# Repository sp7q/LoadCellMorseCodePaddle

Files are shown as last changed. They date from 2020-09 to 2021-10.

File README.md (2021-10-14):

# LoadCellMorseCodePaddle
Load cell morse code paddle

This is a concept of using load cell as Morse Code paddle
Advantages :
- easy mechanical apply
- no moving parts
- fast and quiet
- cheap - Trinket + laod cells + AD ~25$
- auto calibration - no readjustment needed

In TrinketShielPaddle folde You can find KiCAD files + production files ready to send to *PCB make comapny 

Some challenges during during construction :

Assumpion - max speed 100 WPM

Sume usefull link about timing:
https://morsecode.world/international/timing.html

100WPM - 1dot = 12ms

AD requirements : 
Refering to Nyquist–Shannon law https://en.wikipedia.org/wiki/Nyquist%E2%80%93Shannon_sampling_theorem sampling rate should be at least 167 SPS

Load cell gives differential voltage: ~0-1.5mV

ADS1115 - 16bit(12bit ADS1015), 860SPS, lowest range 256mV, Comparator, differential mesurement
- 860SPS - OK
- 16bit - OK - 0.0039mV/bit (ADS1015 - 0.0625mV/bit - too small resolution vs 0-1.5mV range)
- 256mV - bit too low (do You know some AD with gain >16 and built in comparator - then smaller resolution is requiered)
- Comparator - as a requierement ! - comparator output drives executive transistor directly
- Differential mesurement - requre for 4 wire load cell

Battery alert
  - battery should never drop below 3.0V
  - there is ~0.3V drop on diode+regulator (ATTINY85 should work properly till 2.7)
  - Vcc measure using internal 1.1 reference
  - 3.1 - drop = 2.8 = alert 
  - 3.0 - drop = alert + lock paddle 

TODO : 
- AD1115_wa lib cleaning
- other A/D ?
- i2c connection autodiagnose work on Arduino Nano but not on Trinket
- Fully printed housing + paddles will be nice addon (OpenSCAD)
- E/V/HST test - passed HST by SP7VV
- issue with charging circuit
- after some time of use in setup mode paddle start working in reverse mode, need to be pulled instead of pushed - partially done:
      -poor chineese load cell change their "zero" point in time, also beacuse of that new approach with autocalibration is done
      -setup part should done with same approach as well TBD

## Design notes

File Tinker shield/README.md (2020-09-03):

Shield for TRINKET ATTINY85

Found 2 bugs (03-09-2020 fixed):
 - output swapped
 - lack of pullup resistors on ALRT

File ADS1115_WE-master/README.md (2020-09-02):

# ADS1115_WE
An Arduino library for the 16-bit, 4 channel ADS1115 ADC with gain and alert functions.

I have have tried to optimize the library for convenience to use. If you try the examples I recommend to start with Single_Shot.ino. You'll find more details here soon: https://wolles-elektronikkiste.de/ads1115.

All features of the ADS1115 are implemented, including alert functions. 

If you like the library it would be cool if you can give it a star. If you find bugs, please inform me. 

/////////////////////////////////////////////////////////////////////////////////////////////////////////////

I've edited this lib to get raw data form AD instead of calculating mV

TODO :
- clean up and leave only function necessary for my project purpose

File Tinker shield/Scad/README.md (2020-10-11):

Some idea of mechanical solution and use as case aluminum profile 40x40x2 - 50mm long

U can also find paddles thata I used for this project - paddle is prepared for M3 holes in load cell

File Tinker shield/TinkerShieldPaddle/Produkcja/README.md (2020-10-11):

Production files that You can send directly to *PCB.com company

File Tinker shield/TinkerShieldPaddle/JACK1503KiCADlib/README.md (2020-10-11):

KiCAD lib for JACK socket

https://www.tme.eu/pl/details/1503-02/zlacza-jack/lumberg/1503-02/

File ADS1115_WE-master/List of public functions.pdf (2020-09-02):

Function | Parameters | what it does
void reset( ) | none | Resets the ADS1115. Be careful this function uses the I2C general call reset. Therefore all devices listening to general calls will be resetted.
bool init ( ) | none | Sets the Configuration Register to default values. Returns false if the ADS1115 is not connected
void setAlertPinMode( mode ) | ADS1115_ASSERT_AFTER_X with X = 1, 2, 4; or: ADS1115_DISABLE_ALERT (default) | When alert limits are set, this function defines after how many out of range samples the alarm pin will assert. When the alert pin is set to conversion ready alert, you also need call this function with any parameter except ADS1115_DISABLE_ALERT. Which one you choose exactly doesn't matter.
void setAlertLatch( mode ) | ADS1115_LATCH_DISABLED ADS1115_LATCH_ENABLED | When the alert latch is enabled, the alert pin will be active until you call clearAlert or until you call getResult_V / getResult_mV. When disabled, the alert pin will be deactivated, if the results are within limits.
void setAlertPol( polarity ) | ADS1115_ACTIVE_HIGH ADS1115_ACTIVE_LOW (default) | The alert pin can be set active-high or active-low
void setAlertModeAndLimit_V( mode, upper limit, lower limit ) | mode: ADS1115_MAX_LIMIT ADS1115_WINDOW limits: voltage [V] | In max limit mode the alert pin will be active when the max limit is exceeded. The pin will be deactivated again, when the the results are below the lower limit (if latch is not enabled) In the window mode the alert pin will be active when result are out of the window limits. It will be deactivated, when results are in the window limits again (if latch is not enabled).
void setConvRate( rate ) | ADS1115_X _SPS with X = 8, 16, 32, 64, 128, 250, 475, 860 | Sets the conversion rate in number of samples per second (SPS).
void setMeasureMode( mode ) | ADS1115_CONTINUOUS ADS1115_SINGLE | Sets continuous or single-shot mode. In single-shot mode the measurements need to be triggered manually (startSingleMeasurement). After a single-shot measurement the device goes into power-down mode.
void setVoltageRange_mV( range ) | ADS1115_RANGE_X with X = 6144, 4096, 2048, 1024, 0512, 0256 | Sets voltage range in mV and therefore the gain amplifier. The range is alway from -X to +X. Voltages applied to the input pins shall not exceed VCC + 0.3 Volt. If you change the range the compare registers will be updated automatically.
void setCompareChannels( ) | ADS1115_COMP_X with X = 0_1, 0_2, 1_3, 2_3, 0_GND, 1_GND, 2_GND, 3_GND | Sets the channels to be compared channels to be compared to GND
bool isBusy( ) | none | Reads the Conversion Ready flag. Works only in single-shot mode.
void startSingleMeasurement( ) | none | Triggers a single-shot measurement.
void getResult_V( ) / getResult_mV( ) | none | Returns the result currently available in the conversion register either in Volt or Millivolt. It does not wait for the current conversion to be completed.
void setAlertPinToConversionReady( ) | none | The alert pin will be active when a conversion is completed. You will also need to call the setAlertPinMode function. You can either use the alert pin for limit alerts or conversion ready alerts, not both in parallel.
void clearAlert( ) | none | When the alert latch is enabled, the alert will be active until you call this function or until you call getResult_V / getResult_mV.

## List of commands (public functions) of the ADS1115_WE library

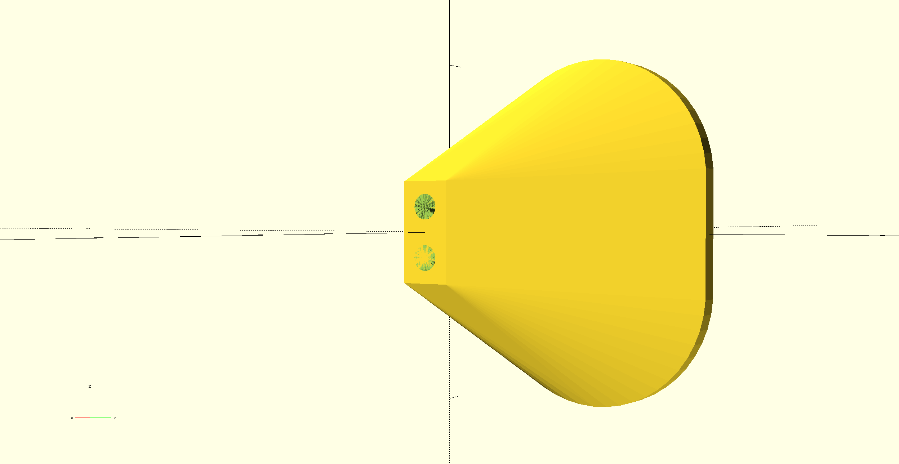
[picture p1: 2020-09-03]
Tinker shield/Scad/paddleuni_view.png

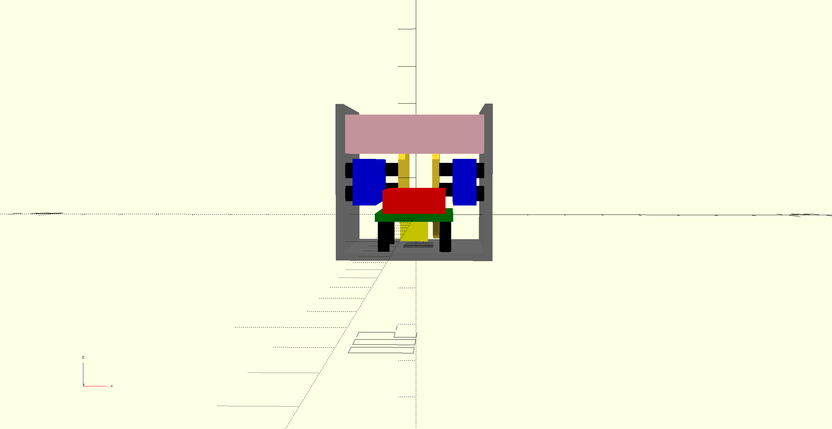
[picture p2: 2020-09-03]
Tinker shield/Scad/view3.png

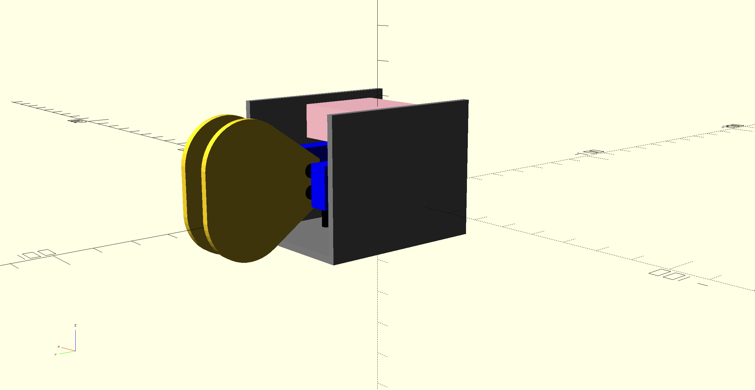
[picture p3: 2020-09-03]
Tinker shield/Scad/view1.png

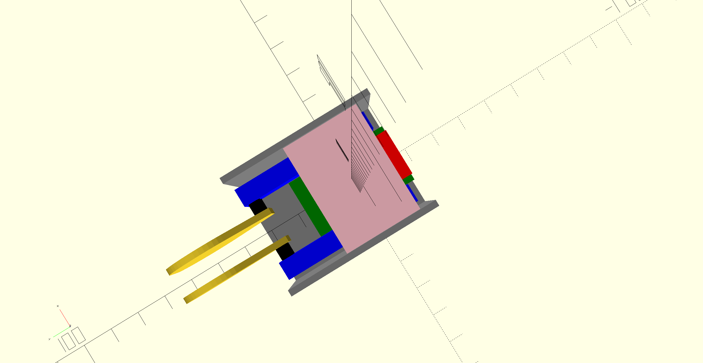
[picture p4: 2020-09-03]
Tinker shield/Scad/view2.png

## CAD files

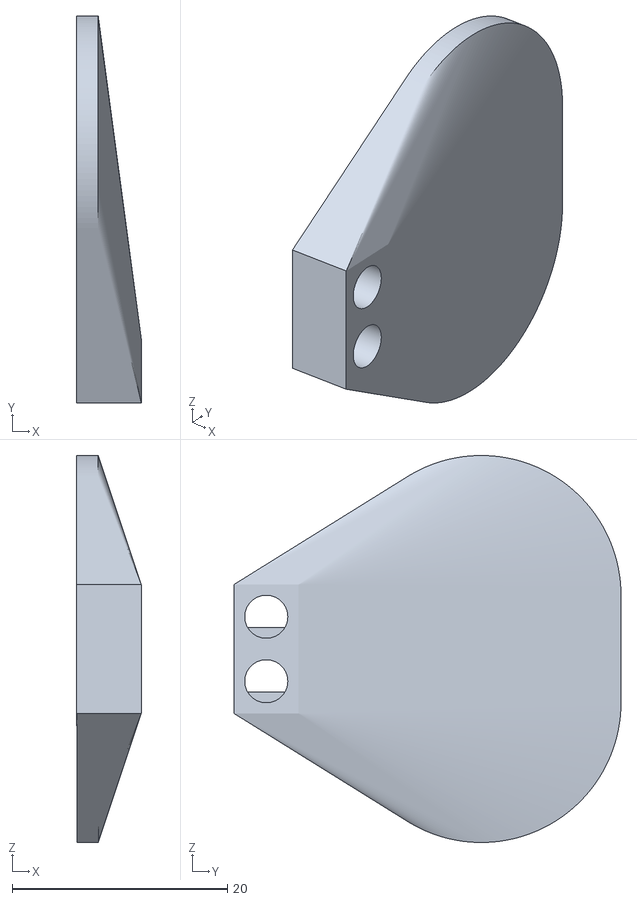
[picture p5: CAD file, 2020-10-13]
Tinker shield/Scad/paddleUniM4.stl
6.00 x 36.0 x 36.0

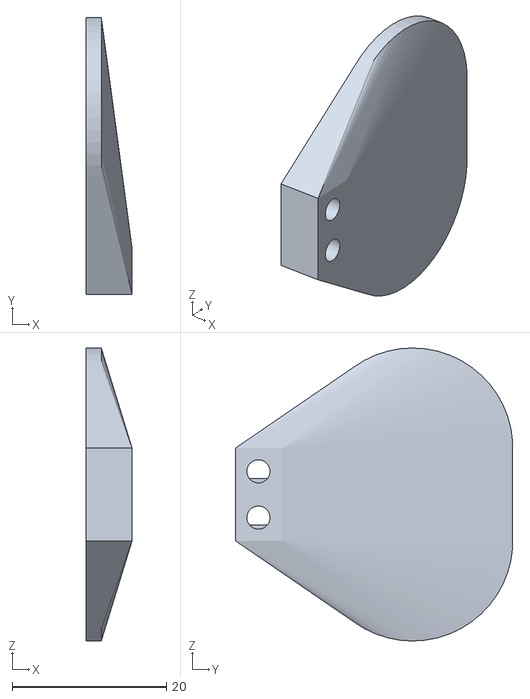
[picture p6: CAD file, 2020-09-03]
Tinker shield/Scad/paddleUni.stl
6.00 x 36.0 x 38.0

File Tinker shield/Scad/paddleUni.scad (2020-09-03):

difference(){
//otwor pod srube    


hull(){
translate([2,0,0]){
cube([6,6,12],true);    
    }     

    
translate([0,20,6]){
rotate([0,90,0]){
cylinder(2,13,13,$fn=50,true);
}
}

translate([0,20,-6]){
rotate([0,90,0]){
cylinder(2,13,13,$fn=50,true);
}
}

}

translate([2,0,3]){
rotate([0,90,0]){
cylinder(6,1.5,1.5,$fn=50,true);
}
}

translate([0,0,3]){
rotate([0,90,0]){
cylinder(2,2,1.5,$fn=50,true);
}
}

translate([2,0,-3]){
rotate([0,90,0]){
cylinder(6,1.5,1.5,$fn=50,true);
}
}
translate([0,0,-3]){
rotate([0,90,0]){
cylinder(2,2,1.5,$fn=50,true);
}
}
}

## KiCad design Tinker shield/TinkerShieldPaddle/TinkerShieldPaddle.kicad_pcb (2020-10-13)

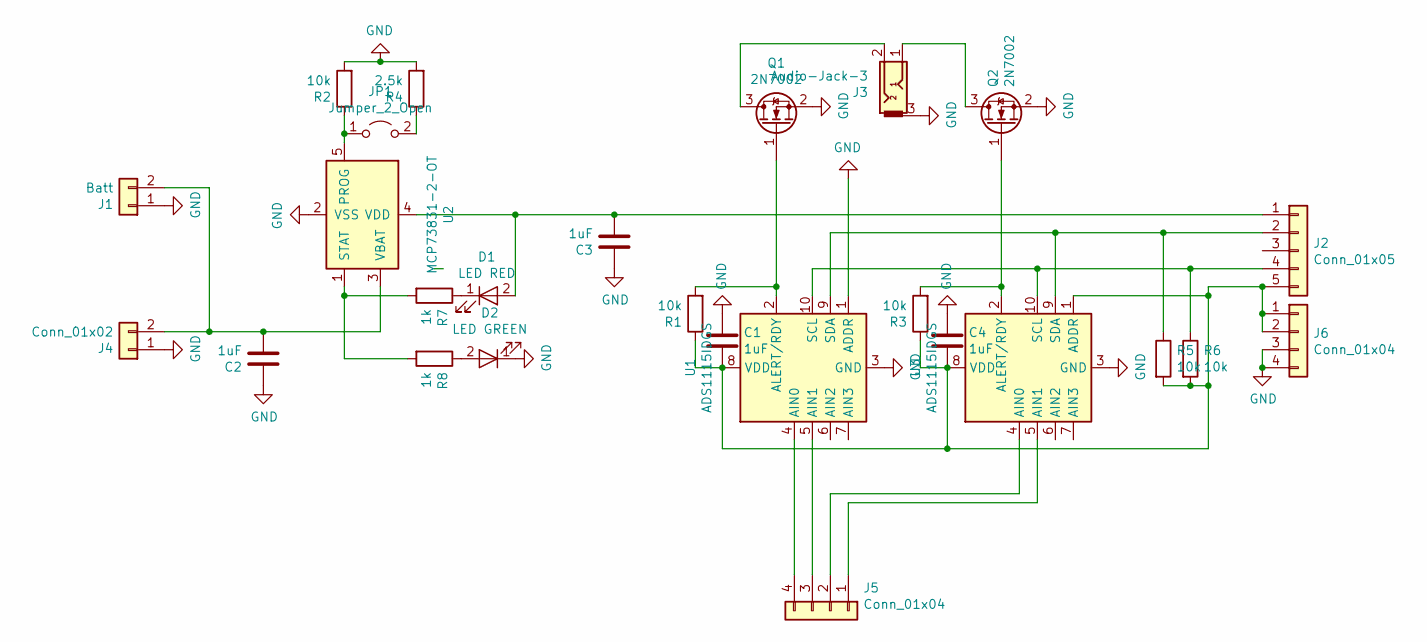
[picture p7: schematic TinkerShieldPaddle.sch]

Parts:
C1, C2, C3, C4: 1uF; C_0805_2012Metric_Pad1.15x1.40mm_HandSolder
D1: LED RED; D_0805_2012Metric_Pad1.15x1.40mm_HandSolder
D2: LED GREEN; D_0805_2012Metric_Pad1.15x1.40mm_HandSolder
J1: Batt; PinHeader_1x02_P2.54mm_Vertical
J2: Conn_01x05; PinHeader_1x05_P2.54mm_Vertical
J3: Audio-Jack-3; Jack_3.5mm_1503_Horizontal
J4: Conn_01x02; PinHeader_1x02_P2.54mm_Vertical
J5, J6: Conn_01x04; PinHeader_1x04_P2.54mm_Vertical
JP1: Jumper_2_Open; SolderJumper-2_P1.3mm_Open_RoundedPad1.0x1.5mm
Q1, Q2: 2N7002; SOT-23
R1, R2, R3, R5, R6: 10k; R_0805_2012Metric_Pad1.15x1.40mm_HandSolder
R4: 2.5k; R_0805_2012Metric_Pad1.15x1.40mm_HandSolder
R7, R8: 1k; R_0805_2012Metric_Pad1.15x1.40mm_HandSolder
U1, U3: ADS1115IDGS; TSSOP-10_3x3mm_P0.5mm
U2: MCP73831-2-OT; SOT-23-5_HandSoldering

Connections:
GND: C1.1, C2.1, C3.1, C4.1, D2.1 (K), J1.1, J3.3, J4.1, J6.3, J6.4, Q1.2 (S), Q2.2 (S), R2.2, R4.2, U1.1 (ADDR), U1.3 (GND), U2.2 (VSS), U3.3 (GND)
unnamed: C1.2, C4.2, J2.5, J6.1, J6.2, R1.1, R3.1, R5.2, R6.2, U1.8 (VDD), U3.1 (ADDR), U3.8 (VDD)
unnamed: C2.2, J1.2, J4.2, U2.3 (VBAT)
unnamed: C3.2, D1.2 (A), J2.1, U2.4 (VDD)
unnamed: D1.1 (K), R7.1
unnamed: D2.2 (A), R8.1
unnamed: J2.2, R5.1, U1.9 (SDA), U3.9 (SDA)
unnamed: J2.4, R6.1, U1.10 (SCL), U3.10 (SCL)
unnamed: J3.1, Q2.3 (D)
unnamed: J3.2, Q1.3 (D)
unnamed: J5.1, U3.5 (AIN1)
unnamed: J5.2, U3.4 (AIN0)
unnamed: J5.3, U1.5 (AIN1)
unnamed: J5.4, U1.4 (AIN0)
unnamed: JP1.1 (A), R2.1, U2.5 (PROG)
unnamed: JP1.2 (B), R4.1
unnamed: Q1.1 (G), R1.2, U1.2 (ALERT/RDY)
unnamed: Q2.1 (G), R3.2, U3.2 (ALERT/RDY)
unnamed: R7.2, R8.2, U2.1 (STAT)

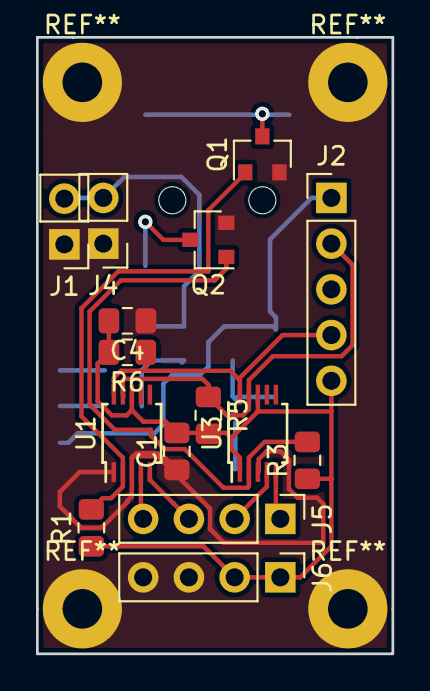
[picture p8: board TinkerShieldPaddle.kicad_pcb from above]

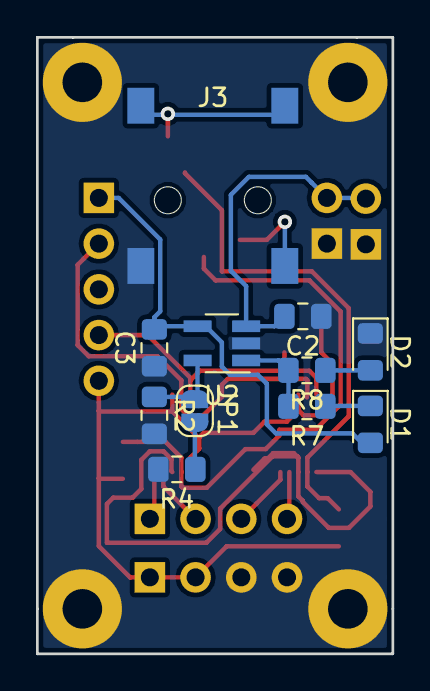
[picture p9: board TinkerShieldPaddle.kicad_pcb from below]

Board: 2 copper layers, 19.8 x 34.2 mm, 26 parts (11 on the bottom side), 19 nets.

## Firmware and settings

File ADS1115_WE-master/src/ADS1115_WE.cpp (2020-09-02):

/*****************************************
* This is a library for the ADS1115 A/D Converter
*
* You'll find an example which should enable you to use the library. 
*
* You are free to use it, change it or build on it. In case you like 
* it, it would be cool if you give it a star.
* 
* If you find bugs, please inform me!
* 
* Written by Wolfgang (Wolle) Ewald
* https://wolles-elektronikkiste.de
*
*******************************************/

#include "ADS1115_WE.h"

ADS1115_WE::ADS1115_WE(int addr){
	i2cAddress = addr;
}

ADS1115_WE::ADS1115_WE(){
	i2cAddress = 0x48;
}

void ADS1115_WE::reset(){
	Wire.beginTransmission(0);
	Wire.write(0x06);
	Wire.endTransmission();
}

bool ADS1115_WE::init(){	
	Wire.beginTransmission(i2cAddress);
	uint8_t success = Wire.endTransmission();
	if(success){
		return 0;
	}
	writeRegister(ADS1115_CONFIG_REG, ADS1115_REG_RESET_VAL);
	setVoltageRange_mV(ADS1115_RANGE_2048);
	writeRegister(ADS1115_LO_THRESH_REG, 0x8000);
	writeRegister(ADS1115_HI_THRESH_REG, 0x7FFF);
	return 1;
}

void ADS1115_WE::setAlertPinMode(ADS1115_COMP_QUE mode){
	uint16_t currentConfReg = readRegister(ADS1115_CONFIG_REG);
	currentConfReg &= ~(0x0003);	
	currentConfReg |= mode;
	writeRegister(ADS1115_CONFIG_REG, currentConfReg);
}

void ADS1115_WE::setAlertLatch(ADS1115_LATCH latch){
	uint16_t currentConfReg = readRegister(ADS1115_CONFIG_REG);
	currentConfReg &= ~(0x0004);	
	currentConfReg |= latch;
	writeRegister(ADS1115_CONFIG_REG, currentConfReg);
}

void ADS1115_WE::setAlertPol(ADS1115_ALERT_POL polarity){
	uint16_t currentConfReg = readRegister(ADS1115_CONFIG_REG);
	currentConfReg &= ~(0x0008);	
	currentConfReg |= polarity;
	writeRegister(ADS1115_CONFIG_REG, currentConfReg);
}

void ADS1115_WE::setAlertModeAndLimit_V(ADS1115_COMP_MODE mode, int hiThres, int loThres){
	uint16_t currentConfReg = readRegister(ADS1115_CONFIG_REG);
	currentConfReg &= ~(0x0010);	
	currentConfReg |= mode;
	writeRegister(ADS1115_CONFIG_REG, currentConfReg);
	//int16_t alertLimit = calcLimit(hiThres);
	int16_t alertLimit = hiThres;
	writeRegister(ADS1115_HI_THRESH_REG, alertLimit);
	//alertLimit = calcLimit(loThres);
	alertLimit = loThres;
	writeRegister(ADS1115_LO_THRESH_REG, alertLimit);
	
}

void ADS1115_WE::setConvRate(ADS1115_CONV_RATE rate){
	uint16_t currentConfReg = readRegister(ADS1115_CONFIG_REG);
	currentConfReg &= ~(0x00E0);	
	currentConfReg |= rate;
	writeRegister(ADS1115_CONFIG_REG, currentConfReg);
}
		
void ADS1115_WE::setMeasureMode(ADS1115_MEASURE_MODE mode){
	uint16_t currentConfReg = readRegister(ADS1115_CONFIG_REG);
	currentConfReg &= ~(0x0100);	
	currentConfReg |= mode;
	writeRegister(ADS1115_CONFIG_REG, currentConfReg);
}

void ADS1115_WE::setVoltageRange_mV(ADS1115_RANGE range){
	uint16_t currentVoltageRange = voltageRange;
	uint16_t currentConfReg = readRegister(ADS1115_CONFIG_REG);
	uint16_t currentRange = (currentConfReg >> 9) & 7;
	uint16_t currentAlertPinMode = currentConfReg & 3;
	
	setMeasureMode(ADS1115_SINGLE);
	
	switch(range){
		case ADS1115_RANGE_6144:
			voltageRange = 6144;
			break;
		case ADS1115_RANGE_4096:
			voltageRange = 4096;
			break;
		case ADS1115_RANGE_2048:
			voltageRange = 2048;
			break;
		case ADS1115_RANGE_1024:
			voltageRange = 1024;
			break;
		case ADS1115_RANGE_0512:
			voltageRange = 512;
			break;
		case ADS1115_RANGE_0256:
			voltageRange = 256;
			break;
	}
	
	if ((currentRange != range) && (currentAlertPinMode != ADS1115_DISABLE_ALERT)){
		int16_t alertLimit = readRegister(ADS1115_HI_THRESH_REG);
		alertLimit = alertLimit * (currentVoltageRange * 1.0 / voltageRange);
		writeRegister(ADS1115_HI_THRESH_REG, alertLimit);
		
		alertLimit = readRegister(ADS1115_LO_THRESH_REG);
		alertLimit = alertLimit * (currentVoltageRange * 1.0 / voltageRange);
		writeRegister(ADS1115_LO_THRESH_REG, alertLimit);
	}
	
	currentConfReg &= ~(0x0E00);	
	currentConfReg |= range;
	writeRegister(ADS1115_CONFIG_REG, currentConfReg);
}

void ADS1115_WE::setCompareChannels(ADS1115_MUX mux){
	uint16_t currentConfReg = readRegister(ADS1115_CONFIG_REG);
	currentConfReg &= ~(0x7000);	
	currentConfReg |= (mux);
	writeRegister(ADS1115_CONFIG_REG, currentConfReg);	
}
	
bool ADS1115_WE::isBusy(){
	uint16_t currentConfReg = readRegister(ADS1115_CONFIG_REG);
	return (!(currentConfReg>>15) & 1);
}
	
void ADS1115_WE::startSingleMeasurement(){
	uint16_t currentConfReg = readRegister(ADS1115_CONFIG_REG);
	currentConfReg |= (1 << 15);
	writeRegister(ADS1115_CONFIG_REG, currentConfReg);
}
	
float ADS1115_WE::getResult_V(){
	int16_t rawResult = readRegister(ADS1115_CONV_REG);
	float result = (rawResult * 1.0 / ADS1115_REG_FACTOR) * voltageRange/1000;
	return result;	
}

float ADS1115_WE::getResult_mV(){
	int16_t rawResult = readRegister(ADS1115_CONV_REG);
	//float result = (rawResult * 1.0 / ADS1115_REG_FACTOR) * voltageRange;
	float result = rawResult;
	return result;
}

int16_t ADS1115_WE::getResultWithRange(int16_t min, int16_t max){
	int16_t rawResult = readRegister(ADS1115_CONV_REG);
	//rawResult = (int) (rawResult * (voltageRange * 1.0 / 6144));
	int16_t result = 0;
	result = map(rawResult, 0, 32767, min, max);
	return result;
}


void ADS1115_WE::setAlertPinToConversionReady(){
	writeRegister(ADS1115_LO_THRESH_REG, (0<<15));
	writeRegister(ADS1115_HI_THRESH_REG, (1<<15));
}

void ADS1115_WE::clearAlert(){
	readRegister(ADS1115_CONV_REG);
}

/************************************************ 
	private functions
*************************************************/

int16_t ADS1115_WE::calcLimit(float rawLimit){
	int16_t limit = (int16_t)((rawLimit * ADS1115_REG_FACTOR / voltageRange)*1000);
	return limit;
}

uint8_t ADS1115_WE::writeRegister(uint8_t reg, uint16_t val){
  Wire.beginTransmission(i2cAddress);
  uint8_t lVal = val & 255;
  uint8_t hVal = val >> 8;
  Wire.write(reg);
  Wire.write(hVal);
  Wire.write(lVal);
  return Wire.endTransmission();
}
  
uint16_t ADS1115_WE::readRegister(uint8_t reg){
  uint8_t MSByte = 0, LSByte = 0;
  uint16_t regValue = 0;
  Wire.beginTransmission(i2cAddress);
  Wire.write(reg);
  Wire.endTransmission();
  Wire.requestFrom(i2cAddress,2);
  if(Wire.available()){
    MSByte = Wire.read();
    LSByte = Wire.read();
  }
  regValue = (MSByte<<8) + LSByte;
  return regValue;
}
	

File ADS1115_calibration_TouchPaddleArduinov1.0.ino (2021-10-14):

//ADS1115 - with calibration
// different approach - because battery is discharging and power supply vary in time calibration should be done on power up.
//to do - correct setup part
#include <tinysnore.h> //lib for ATTINY85
#include<ADS1115_WE.h> //lib was edited to give raw data instead of mV
#include<Wire.h>
#include <EEPROM.h>
#define I2C_ADDRESS_1 0x48
#define I2C_ADDRESS_2 0x49
ADS1115_WE adc(I2C_ADDRESS_1);
ADS1115_WE adc2(I2C_ADDRESS_2);

int result = 0;
int result2 = 0;
int resultb = 0;
int result2b = 0;
int led = 1; //1 - Trinket, 13 - Arduino
int sensitivity;
int sensitivityNow;
int leftNow;    
int rightNow;
int leftOn = 100;      //left paddle treshold
int leftOnAbs;   //left paddle absolute value treshold 
int leftOff = 80;     //left paddle off treshold
int rightOn = 100;     //right paddle treshold 
int rightOnAbs;   //right paddle absolute value treshold 
int rightOff = 80;   //right paddle off treshold
int hysteresis = 7; //hysteresis
int configMode = 0;
int time1;  //time for setup mode purpose
int time2;  //time for setup mode purpose

void setup() {
  pinMode(led, OUTPUT); 
  Wire.begin();
  //Serial.begin(250000);
  //this warning dont work on ATTINY dont know why ....
 /* 
  while(!adc2.init()){
        blink(20);
        delay(500);
//        Serial.println("adc2 not found");
  }

  while(!adc.init()){
        blink(40);
        delay(500);
//        Serial.println("adc not found");
  }
*/
  EEPROM.get(0,sensitivity);
//  EEPROM.get(2,leftOn);  
//  EEPROM.get(4,leftOff);  
//  EEPROM.get(6,rightOn); 
//  EEPROM.get(8,rightOff); 
  

  
  adc.setVoltageRange_mV(ADS1115_RANGE_0256); //amplifier gain
  adc.setCompareChannels(ADS1115_COMP_0_1); //differential measurement
  adc.setConvRate(ADS1115_860_SPS); //samples pre second 
  adc.setMeasureMode(ADS1115_CONTINUOUS); //Continous mode
  adc.setAlertPinMode(ADS1115_ASSERT_AFTER_1); //after how many measurments ALRT output is set
  adc.setAlertModeAndLimit_V(ADS1115_MAX_LIMIT, leftOn, leftOff); //Comparator values Hightreshold then LowTreshold 
  adc.setAlertPol(ADS1115_ACT_HIGH); //ALRT polarity

  adc2.setVoltageRange_mV(ADS1115_RANGE_0256); //amplifier gain
  adc2.setCompareChannels(ADS1115_COMP_0_1); //differential measurement
  adc2.setConvRate(ADS1115_860_SPS); //samples pre second 
  adc2.setMeasureMode(ADS1115_CONTINUOUS); //Continous mode
  adc2.setAlertPinMode(ADS1115_ASSERT_AFTER_1); //after how many measurments ALRT output is set
  adc2.setAlertModeAndLimit_V(ADS1115_MAX_LIMIT, rightOn, rightOff); //Comparator values Hightreshold then LowTreshold 
  adc2.setAlertPol(ADS1115_ACT_HIGH); //ALRT polarity
  delay(50);
  result = adc.getResult_mV(); 
  result2 = adc2.getResult_mV();
  blink(sensitivity);
  delay(500);
  resultb = adc.getResult_mV(); 
  result2b = adc2.getResult_mV();  
  if ((resultb > result) && (result2b > result2)){
      configMode = 1;
      blink(100);
      time1 = millis();
    }
  if (!configMode) {
    //autocalibration
    leftOn = result + sensitivity;  //measure free state and do the calibration 
          if (leftOn >= 0){
            leftOff = leftOn - hysteresis;
            }
            else {
              leftOnAbs = abs(leftOn);
              leftOff = -hysteresis - leftOnAbs;
              }
    rightOn = result2 + sensitivity;
           if (rightOn >= 0){
            rightOff = rightOn - hysteresis;
            }
            else {
              rightOnAbs = abs(rightOn);
              rightOff = -hysteresis - rightOnAbs;
              }  
  
  //apply tresholds after calibration
    adc.setAlertModeAndLimit_V(ADS1115_MAX_LIMIT, leftOn, leftOff); //Comparator values Hightreshold then LowTreshold
    adc2.setAlertModeAndLimit_V(ADS1115_MAX_LIMIT, rightOn, rightOff); //Comparator values Hightreshold then LowTreshold
  }  
/*for testing purpose
Serial.print(" leftOn ");
Serial.print(leftOn);
Serial.print(" leftOff ");
Serial.print(leftOff);
Serial.print(" rightOn ");
Serial.print(rightOn);
Serial.print(" rightOff ");
Serial.println(rightOff);
*/
}

void loop() {
  if (configMode){
  config_loop();
  }
  else {
  main_loop();
  }
}

void main_loop() {
  //snore lib for ATTINY85 - uC to sleep mode
  snore(10000);
  while (readVcc() < 3000){
    adc.setAlertModeAndLimit_V(ADS1115_MAX_LIMIT, 2000, 1900);
    adc2.setAlertModeAndLimit_V(ADS1115_MAX_LIMIT, 2000, 1900);
    digitalWrite(led, HIGH);
    delay(100);
    digitalWrite(led, LOW);
    delay(100);    
  }
  if (readVcc() < 3100){
    digitalWrite(led, HIGH);
  }
  else{
    digitalWrite(led, LOW);
  } 

/*
  //only for test purpose
  result = adc.getResult_mV(); 
  result2 = adc2.getResult_mV();

Serial.print(" result ");
Serial.print(result);
Serial.print(" result2 ");
Serial.println(result2);
  */
}

  

void config_loop(){
  
  
  result = adc.getResult_mV(); 
  result2 = adc2.getResult_mV();
  time2 = millis(); 

//autocalibration
leftOn = result + sensitivity;  //measure free state and do the calibration 
      if (leftOn >= 0){
        leftOff = leftOn - hysteresis;
        }
        else {
          leftOnAbs = abs(leftOn);
          leftOff = -hysteresis - leftOnAbs;
          }
rightOn = result2 + sensitivity;
       if (rightOn >= 0){
        rightOff = rightOn - hysteresis;
        }
        else {
          rightOnAbs = abs(rightOn);
          rightOff = -hysteresis - rightOnAbs;
          }  

//exit after 5s and write sensitivity
  if ((time2-time1)>5000){
      blink(sensitivity);
 
      EEPROM.put(0,sensitivity);   //store sensitivity permanent when leaving
//      EEPROM.put(2,leftOn);  
//      EEPROM.put(4,leftOff);  
//      EEPROM.put(6,rightOn); 
//      EEPROM.put(8,rightOff); 
      
      adc.setAlertModeAndLimit_V(ADS1115_MAX_LIMIT, leftOn, leftOff);
      adc2.setAlertModeAndLimit_V(ADS1115_MAX_LIMIT, rightOn, rightOff);
      configMode = 0;
    }

//set paddle status
  if ((result > 20) && (leftNow == 0)) {
   leftNow = 1;
   sensitivity = sensitivity + 10;
   }
  if (result < 10) {
   leftNow = 0;
  }
  if ((result2 > 20) && (rightNow == 0)) {
   rightNow = 1;
   sensitivity = sensitivity - 10;
   }
   if (result2 < 10) {
   rightNow = 0;
  }
//set sensitivity
if (sensitivity != sensitivityNow)
  switch (sensitivity){
      case 0:
      sensitivity = 10;
      time1 = millis();
      break;
    case 10:
      sensitivityNow = sensitivity;
      blink(sensitivityNow);
      time1 = millis();
      break;
    case 20:
      sensitivityNow = sensitivity;
      blink(sensitivityNow);
      time1 = millis();
      break;
    case 30:
      sensitivityNow = sensitivity;
      blink(sensitivityNow);
      time1 = millis();
      break;
    case 40:
      sensitivityNow = sensitivity;
      blink(sensitivityNow);
      time1 = millis();
      break;
    case 50:
      sensitivityNow = sensitivity;
      blink(sensitivityNow);
      time1 = millis();
      break;
    case 60:
      sensitivityNow = sensitivity;
      blink(sensitivityNow);
      time1 = millis();
      break;
    case 70:
      sensitivity = 60;
      time1 = millis();
      break;
    default:
      sensitivity = 10;
      time1 = millis();
      break;
    }  
}



void blink(int amount){
      for(int x = 0; x < amount; x = x+10){
      digitalWrite(led, HIGH);
      delay(50);
      digitalWrite(led, LOW);
      delay(100);
      }
    
  }
//Only for ATTINY85
long readVcc() {
  // Read 1.1V reference against AVcc
  // set the reference to Vcc and the measurement to the internal 1.1V reference
  //https://provideyourown.com/2012/secret-arduino-voltmeter-measure-battery-voltage/
  #if defined(__AVR_ATmega32U4__) || defined(__AVR_ATmega1280__) || defined(__AVR_ATmega2560__)
    ADMUX = _BV(REFS0) | _BV(MUX4) | _BV(MUX3) | _BV(MUX2) | _BV(MUX1);
  #elif defined (__AVR_ATtiny24__) || defined(__AVR_ATtiny44__) || defined(__AVR_ATtiny84__)
    ADMUX = _BV(MUX5) | _BV(MUX0);
  #elif defined (__AVR_ATtiny25__) || defined(__AVR_ATtiny45__) || defined(__AVR_ATtiny85__)
    ADMUX = _BV(MUX3) | _BV(MUX2);
  #else
    ADMUX = _BV(REFS0) | _BV(MUX3) | _BV(MUX2) | _BV(MUX1);
  #endif  

  delay(2); // Wait for Vref to settle
  ADCSRA |= _BV(ADSC); // Start conversion
  while (bit_is_set(ADCSRA,ADSC)); // measuring

  uint8_t low  = ADCL; // must read ADCL first - it then locks ADCH  
  uint8_t high = ADCH; // unlocks both

  long result = (high<<8) | low;

  result = 1125300L / result; // Calculate Vcc (in mV); 1125300 = 1.1*1023*1000
  return result; // Vcc in millivolts
}  
